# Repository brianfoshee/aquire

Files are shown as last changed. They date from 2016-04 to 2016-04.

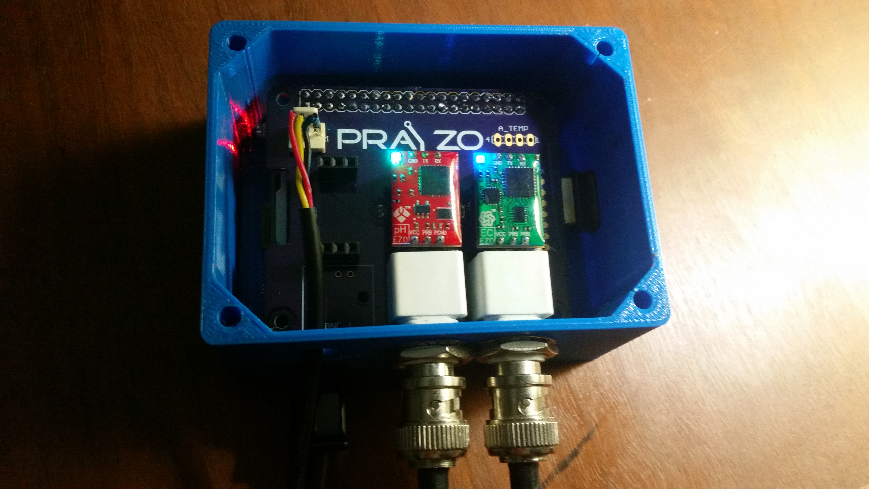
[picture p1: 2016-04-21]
20160420_211440.jpg

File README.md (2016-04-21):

## Turn your Raspberry Pi into a scientific grade hydroponic/aquaponic monitoring system!

### Hardware
- Raspberry Pi A+
- Raspberry Pi Supported Wifi Card
- Printed Circuit Board
  - BNC Right Angle PCB Mount
  - 100k SMD Resistor
  - 2x20 Pin 2.54mm Double Row Female Pin Header
  - 1x3 pins 2.54mm Female Header Straight (X2)
  - Atlas PH Circuit (Set to i2c mode)
  - Atlas EC Circuit (Set to i2c mode)
  - PH Probe (Atlas or another that uses BNC connector)
  - EC Probe (Atlas or another that uses BNC connector)
  - DS18B20 Waterproof Digital Temperature Sensor

### Firmware
- Written in Go 
- Communicates with Atlas Sceintic chips via I2C and DS18B20 via 1-wire
- Readings are transmitted via UDP to Statsd/Graphite for data storage and reporting

### Weatherproof Case (3D Printable)
- http://www.thingiverse.com/thing:1463063

### Viewing your data
- Once your device is online, send Brian or Nathan a private message and we'll provide you with a link to view your data

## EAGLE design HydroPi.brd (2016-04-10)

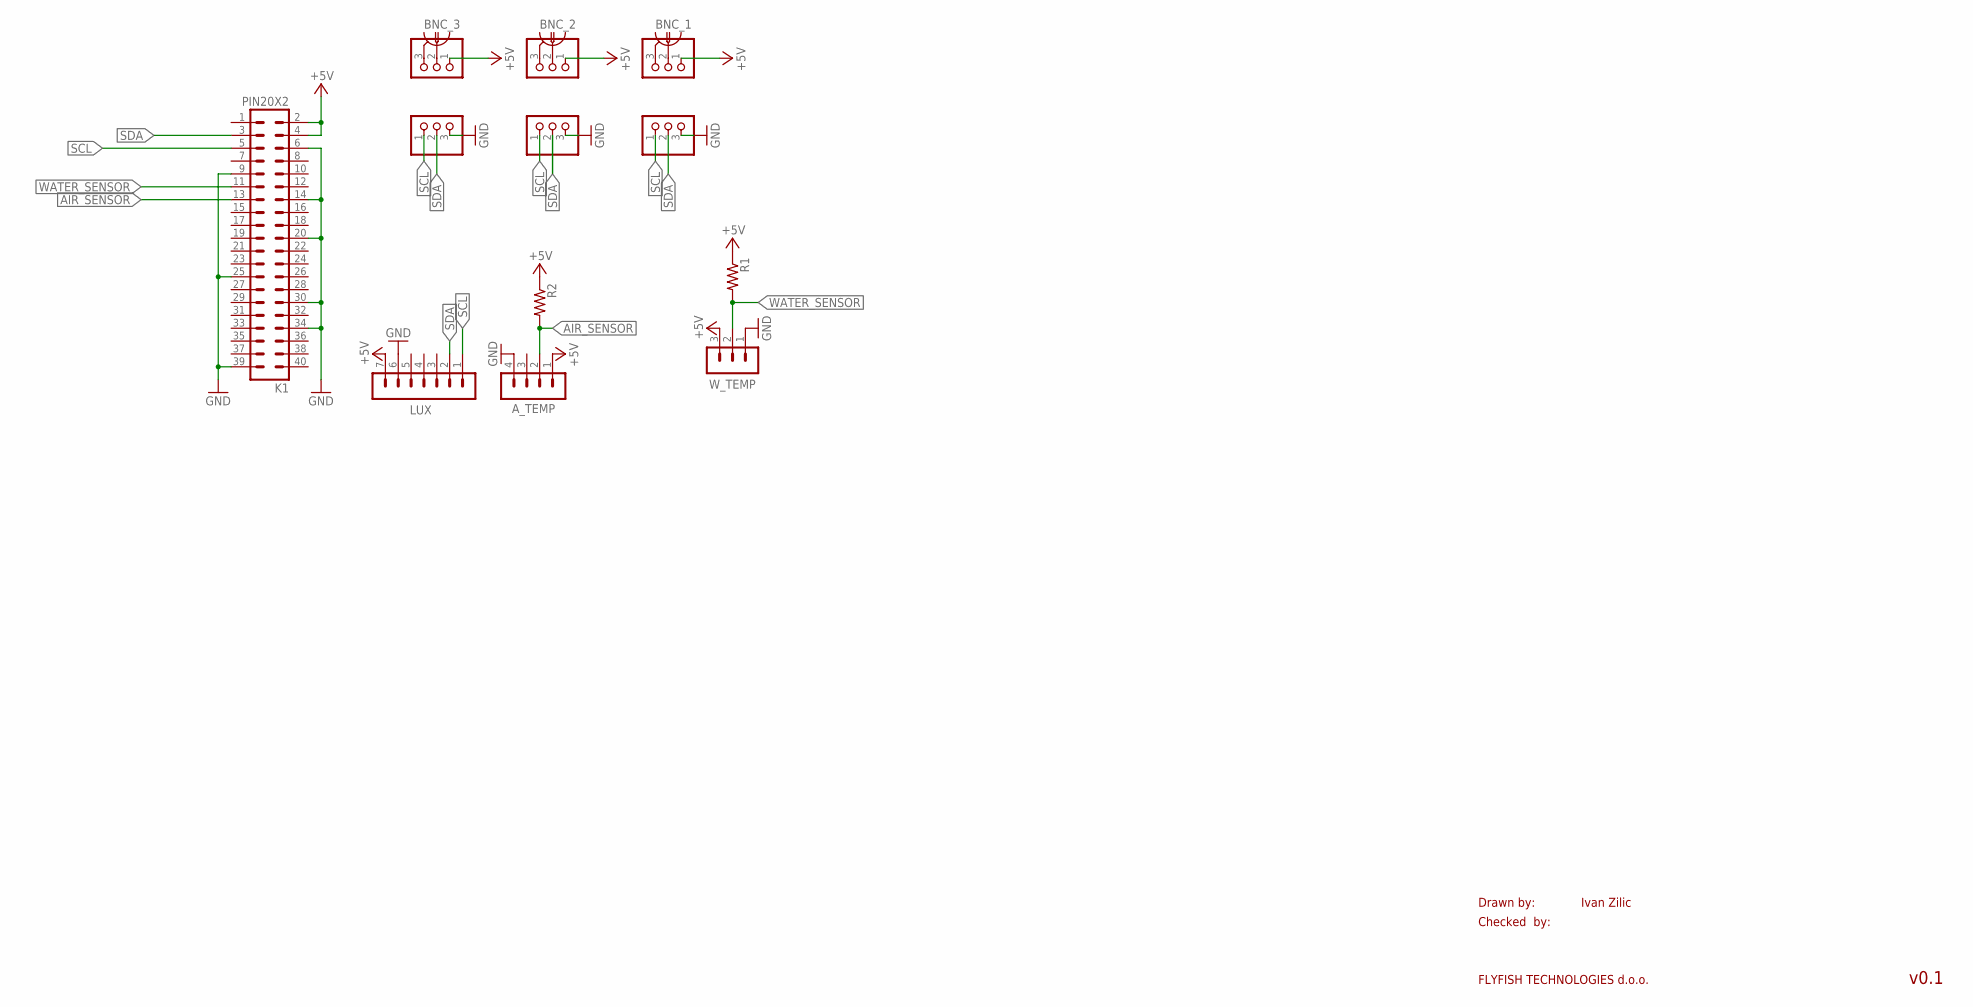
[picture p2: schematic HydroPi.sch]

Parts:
A_TEMP: MA04-1
BNC_1, BNC_2, BNC_3: 1-227161-0; AMP_227161
JP1, JP2, JP3, JP4, JP5, JP6: PINHD-1X3; 1X03
K1: PIN20X2; PIN_20X2
LUX: MA07-1
R1, R2: R-US_R0805; R0805
W_TEMP: MA03-1

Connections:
+5V: A_TEMP.1, JP1.1, JP2.1, JP5.1, K1.2, K1.4, LUX.7, R1.1, R2.1, W_TEMP.3
AIR_SENSOR: A_TEMP.2, K1.13, R2.2
GND: A_TEMP.4, JP3.3, JP4.3, JP6.3, K1.6, K1.9, K1.14, K1.20, K1.25, K1.30, K1.34, K1.39, LUX.6, W_TEMP.1
unnamed: BNC_1.1, JP1.2
unnamed: BNC_1.2, JP1.3
unnamed: BNC_2.1, JP2.2
unnamed: BNC_2.2, JP2.3
unnamed: BNC_3.1, JP5.2
unnamed: BNC_3.2, JP5.3
SCL: JP3.1, JP4.1, JP6.1, K1.5, LUX.1
SDA: JP3.2, JP4.2, JP6.2, K1.3, LUX.2
WATER_SENSOR: K1.11, R1.2, W_TEMP.2

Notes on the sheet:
Drawn by:
Checked by:
FLYFISH TECHNOLOGIES d.o.o.
Ivan Zilic
v0.1

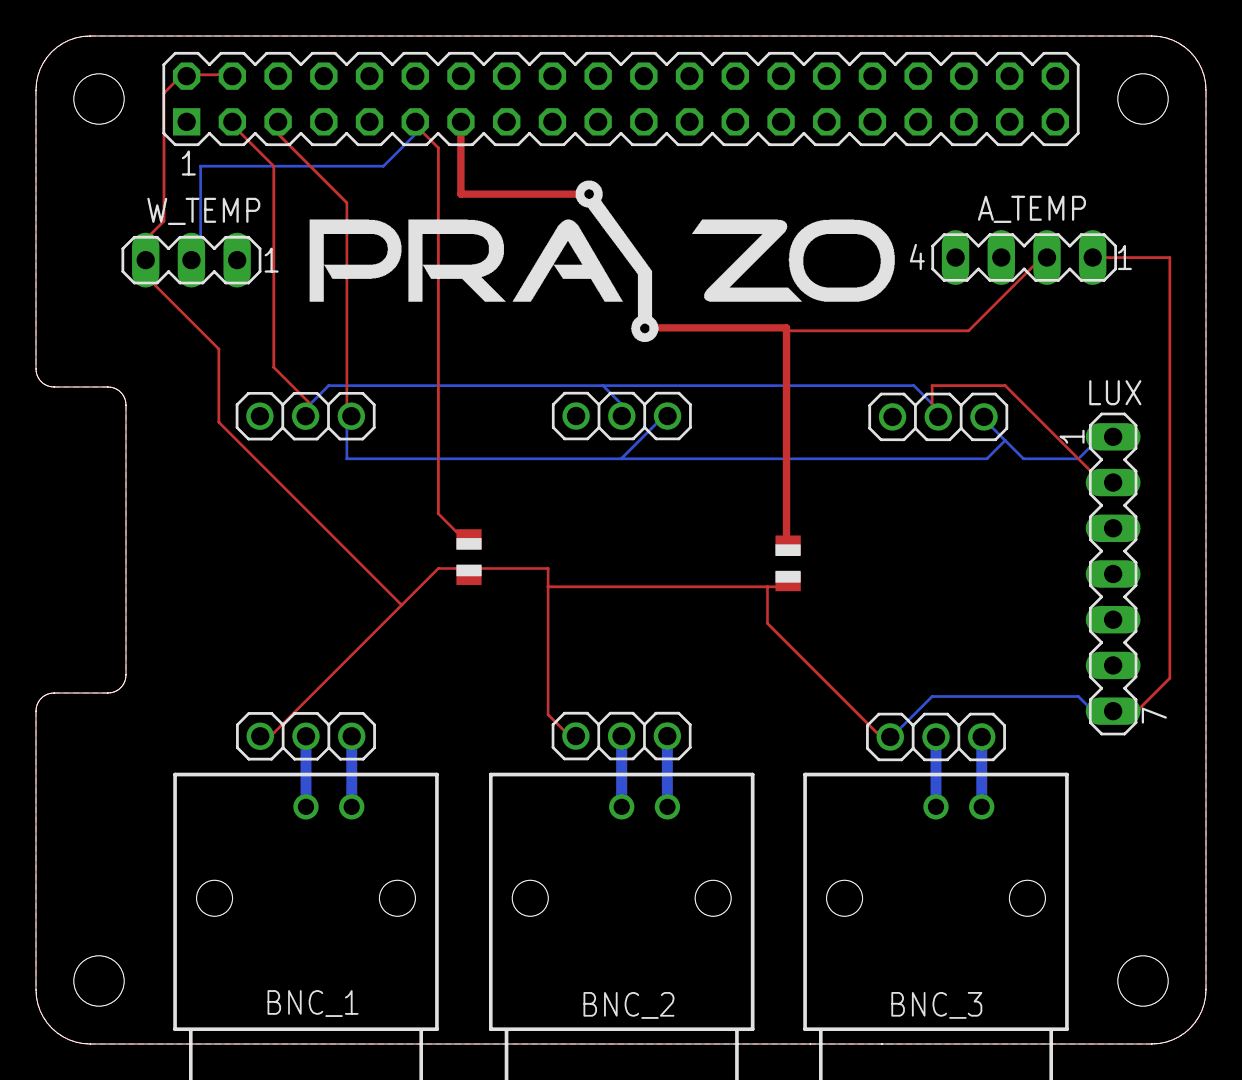
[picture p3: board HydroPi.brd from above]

Board: 2 copper layers, 65.0 x 56.0 mm, 15 parts (0 on the bottom side), 12 nets.

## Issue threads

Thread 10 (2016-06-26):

Uncaught exception reading temperature sensor

nathanprayzo, 2016-06-26:
If a temperature sensor is not connected to the board, the board would ideally assume a standard temperature and proceed to collect data from the sensors available.

Currently, if a temperature sensor is not connected to the board, an uncaught exception preventing the other sensors from being solicited.

```
open /sys/bus/w1/devices/28-031466321eff/id: no such file or directorypanic: runtime error: invalid memory address or nil pointer dereference
[signal 0xb code=0x1 addr=0x14 pc=0x84944]

goroutine 1 [running]:
github.com/brianfoshee/raspberrypi/onewire.(*DS18S20).Read(0x0, 0x2, 0x2, 0x0, 0x0)
        /home/pi/go/src/github.com/brianfoshee/raspberrypi/onewire/ds18s20.go:80 +0x3c
main.main()
        /home/pi/go/src/github.com/brianfoshee/aquire/aquire.go:78 +0x8b0

goroutine 17 [syscall, locked to thread]:
runtime.goexit()
        /usr/local/go/src/runtime/asm_arm.s:1322 +0x4

goroutine 5 [runnable]:
github.com/alexcesaro/statsd.func·005()
        /home/pi/go/src/github.com/alexcesaro/statsd/conn.go:66
created by github.com/alexcesaro/statsd.newConn
        /home/pi/go/src/github.com/alexcesaro/statsd/conn.go:78 +0x520
exit status 2
```

nathanprayzo, 2016-06-26:
@brianfoshee You can now plug and unplug the temp sensor into the board while it's running. If no temp sensor is available on startup it will default to 77F, if the temp sensor is unplugged it will use the previous reading.

brianfoshee, 2016-06-27:
nice!

Closed 2016-06-26.

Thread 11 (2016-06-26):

1wire temperature sensor id is hard coded

nathanprayzo, 2016-06-26:
The 1wire sensor id is hard coded which prevents other temperature sensors from being used.

Closed 2016-06-26.

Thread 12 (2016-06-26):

Index out of range reading temp sensor

nathanprayzo, 2016-06-26:
Introduced an edge condition last commit which can cause an index out of range error when trying to derive 1wire id

Closed 2016-06-26.

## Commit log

2015-04-15 Temperature Dependent Readings, Calibration Functions
2015-04-23 Made I2C handles persistent
2016-03-24 Added support for unique device identifier, solves issue #1
2016-04-03 Refactored ph calibration function to make it more extensible and robust. Fixes #2
2016-04-03 Provides CLI for calibrating atlas chips, only PH currently implemented. Solves issue#3
2016-04-10 PCB Design Files
    [HydroPi.brd, HydroPi.sch]
2016-06-26 Resolved issue #11 - 1wire sensor id now dynamic
